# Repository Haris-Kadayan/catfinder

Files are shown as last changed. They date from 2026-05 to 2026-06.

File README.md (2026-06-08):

catfinder
-
A cat-themed PCB fidget toy with four Cherry MX switches and four LED lights powered by a Seeed Studio XIAO RP2040. It has a Simon Says and a button lights up LED mode. Created for the Hack Club Stasis program.

3D Render
-
This is the 3D render in KiCad with all of the components:

catfinder front

catfinder side

I spent a while with the silkscreen :)

catfinder back

Schematic
-
This is the schematic, which shows all of the connections. This took the least amount of time to make, and to improve organization I used labels:



PCB
-
This is the PCB, this took the most amount of time, the wiring was very dense due to the size of the board. Speaking of the size of the board, it was just under 100mm to save on cost. Because the switches were arragned side by side it was hard to fit everything in that size. It looks messy because of the dual-sided silkscreen:



Code
-
This is the code to the catfinder, this took the second most amount of time. it is programmed in C++ and it has a Simon Says and button lights up LED mode, which is switched by holding all buttons for 5 seconds. I had to figure out how to detect the presses and trigger the LEDs and switches modes. It was kind of hard since im a noob at C++:



BOM
-
| Name | Purpose | Quantity | Total Cost (USD) | Link | Distributor |
|---|---|---|---|---|---|
| PCB | To connect all of the components | 1 | 4 | https://jlcpcb.com/ | JLCPCB |
| Seeed Studio XIAO RP2040 | The brains of the catfinder | 1 | 9.99 | https://www.amazon.com/Microcontroller-Dual-Core-MicroPython-CircuitPython-Interfaces/dp/B09NNVNW7M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 | Amazon |
| Keycaps | The keycap of the catfinder | 1 | Getting when Hack Boy gets approved | https://www.aliexpress.us/item/3256810533781399.html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 | AliExpress  |
| Brown Switches | The buttons on the catfinder | 1 | Getting when Hack Boy gets approved | https://www.aliexpress.us/item/3256811652574937.html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 | AliExpress  |
| LEDs | To light up the catfinder | 1 | Already own | https://www.amazon.com/California-JOS-50-PCS-Colorful/dp/B0CR886L92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 | Amazon |
| Resistors | To limit current to the LEDs | 1 | Already own | https://www.amazon.com/California-JOS-Resistance-CJ50-004-220/dp/B0BDKQSZHM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 | Amazon |

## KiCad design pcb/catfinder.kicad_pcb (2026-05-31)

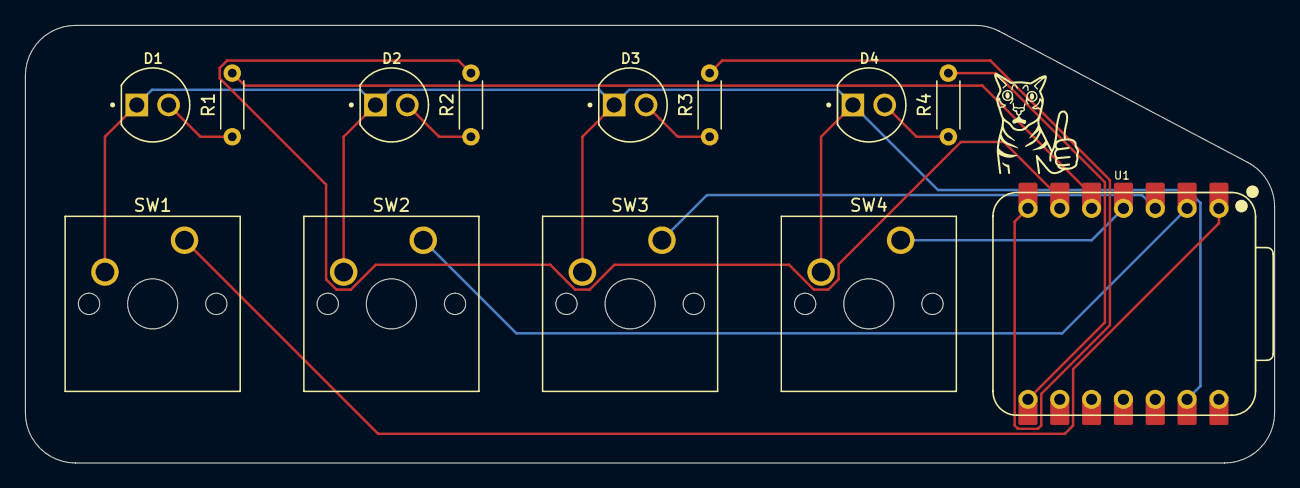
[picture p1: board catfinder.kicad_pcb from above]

Board: 2 copper layers, 99.7 x 34.9 mm, 13 parts (0 on the bottom side), 13 nets.

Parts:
D1, D2, D3, D4: LED; LEDRD254W57D500H1070
R1, R2, R3, R4: R; R_Axial_DIN0204_L3.6mm_D1.6mm_P5.08mm_Horizontal
SW1, SW2, SW3, SW4: SW_Push; SW_Cherry_MX_1.00u_PCB
U1: XIAO-RP2040-DIP

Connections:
GND: D1.C, D2.C, D3.C, D4.C, SW1.2, SW2.2, SW3.2, SW4.2, U1.13 (GND)
LED1: R1.2, U1.5 (P6_SDA_D4)
LED2: R2.2, U1.6 (P7_SCL_D5)
LED3: R3.2, U1.7 (P0_D6_TX)
LED4: R4.2, U1.8 (P1_D7_RX)
unnamed: D1.A, R1.1
unnamed: D2.A, R2.1
unnamed: D3.A, R3.1
unnamed: D4.A, R4.1
SW1: SW1.1, U1.1 (P26_A0_D0)
SW2: SW2.1, U1.2 (P27_A1_D1)
SW3: SW3.1, U1.3 (P28_A2_D2)
SW4: SW4.1, U1.4 (P29_A3_D3)

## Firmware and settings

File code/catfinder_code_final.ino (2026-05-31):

#include <EEPROM.h>

// The code for Haris Kadayan's Catfinder project, created for Hack Club's Stasis Program. :)
// Two modes, Simon Says and button press = LED lights, switch between modes by pressing all buttons for 5 seconds.

int buttons[] = { D0, D1, D2, D3 };
int leds[] = { D4, D5, D6, D7 };

int sequence[50];
int level = 1;

bool testMode = false;
unsigned long allPressedStart = 0;
bool alreadySwitched = false;

int saveAddress = 0;

void setup() {
  EEPROM.begin(16);

  for (int i = 0; i < 4; i++) {
    pinMode(buttons[i], INPUT_PULLUP);
    pinMode(leds[i], OUTPUT);
  }

  int savedMode = EEPROM.read(saveAddress);
  testMode = savedMode == 1;

  randomSeed(analogRead(A0));

  if (!testMode) {
    newGame();
  }
}

void loop() {
  checkModeSwitch();

  if (testMode) {
    buttonLedMode();
  } else {
    simonMode();
  }
}

void checkModeSwitch() {
  bool allPressed =
    digitalRead(buttons[0]) == LOW &&
    digitalRead(buttons[1]) == LOW &&
    digitalRead(buttons[2]) == LOW &&
    digitalRead(buttons[3]) == LOW;

  if (allPressed) {
    if (allPressedStart == 0) {
      allPressedStart = millis();
    }

    if (millis() - allPressedStart >= 5000 && !alreadySwitched) {
      testMode = !testMode;
      alreadySwitched = true;

      EEPROM.write(saveAddress, testMode ? 1 : 0);
      EEPROM.commit();

      modeFlash();

      if (!testMode) {
        newGame();
      }
    }
  } else {
    allPressedStart = 0;
    alreadySwitched = false;
  }
}

void buttonLedMode() {
  for (int i = 0; i < 4; i++) {
    digitalWrite(leds[i], digitalRead(buttons[i]) == LOW ? HIGH : LOW);
  }
}

void simonMode() {
  showSequence();

  for (int i = 0; i < level; i++) {
    int pressed = waitForButton();

    flashLed(pressed, 200);

    if (pressed != sequence[i]) {
      loseAnimation();
      newGame();
      return;
    }
  }

  winStepAnimation();

  level++;

  if (level > 50) {
    level = 50;
  }

  sequence[level - 1] = random(0, 4);

  delay(500);
}

void newGame() {
  level = 1;

  for (int i = 0; i < 50; i++) {
    sequence[i] = random(0, 4);
  }

  startAnimation();
}

void showSequence() {
  delay(500);

  for (int i = 0; i < level; i++) {
    flashLed(sequence[i], 350);
    delay(200);
  }
}

int waitForButton() {
  while (true) {
    checkModeSwitch();

    for (int i = 0; i < 4; i++) {
      if (digitalRead(buttons[i]) == LOW) {
        delay(30);

        while (digitalRead(buttons[i]) == LOW) {
          checkModeSwitch();
        }

        delay(30);
        return i;
      }
    }
  }
}

void flashLed(int ledNumber, int timeOn) {
  digitalWrite(leds[ledNumber], HIGH);
  delay(timeOn);
  digitalWrite(leds[ledNumber], LOW);
}

void startAnimation() {
  for (int i = 0; i < 4; i++) {
    digitalWrite(leds[i], HIGH);
    delay(120);
    digitalWrite(leds[i], LOW);
  }
}

void winStepAnimation() {
  for (int i = 0; i < 4; i++) {
    digitalWrite(leds[i], HIGH);
  }

  delay(150);

  for (int i = 0; i < 4; i++) {
    digitalWrite(leds[i], LOW);
  }
}

void loseAnimation() {
  for (int j = 0; j < 3; j++) {
    for (int i = 0; i < 4; i++) {
      digitalWrite(leds[i], HIGH);
    }

    delay(200);

    for (int i = 0; i < 4; i++) {
      digitalWrite(leds[i], LOW);
    }

    delay(200);
  }
}

void modeFlash() {
  for (int j = 0; j < 2; j++) {
    for (int i = 0; i < 4; i++) {
      digitalWrite(leds[i], HIGH);
    }

    delay(150);

    for (int i = 0; i < 4; i++) {
      digitalWrite(leds[i], LOW);
    }

    delay(150);
  }
}

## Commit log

2026-05-31 Created PCB folder
2026-06-07 Enhance README with additional project details
    Added detailed sections for 3D render, schematic, PCB, and code with images.
2026-06-08 Add BOM table to README
    Added a BOM table listing components, their purposes, quantities, costs, and links.
